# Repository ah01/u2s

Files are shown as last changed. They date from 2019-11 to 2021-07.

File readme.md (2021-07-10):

# USB To Serial Convertor Board

<p align="center">
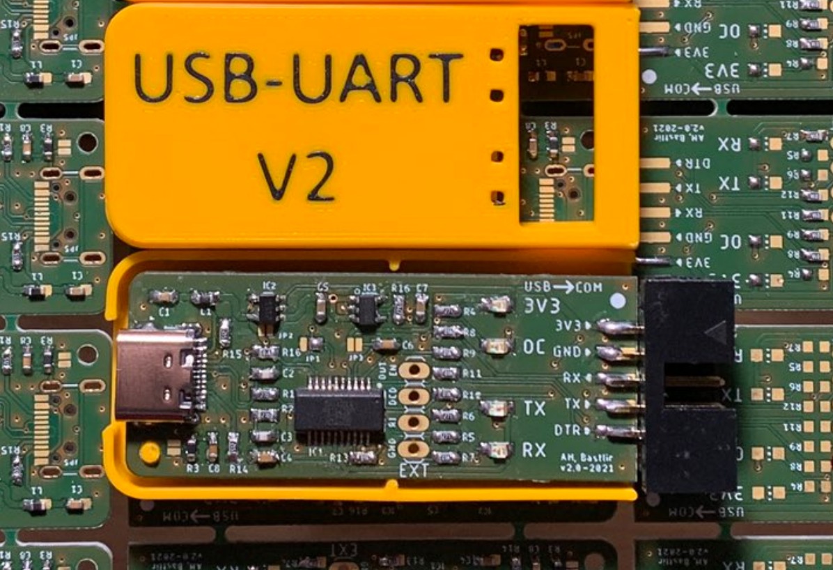
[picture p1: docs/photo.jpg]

</p>

## Features

- Reliable (no CH340 or FTDI232RL clones) – uses [FT231SX](https://ftdichip.com/products/ft231xs/) ([datasheet](https://ftdichip.com/wp-content/uploads/2020/08/DS_FT231X.pdf))
- 3V3 logic but 5V tolerant (no switching needed)
- On board 3V3 regulator (500 mA)
- Over current protection (suitable for development)
- Connector with key (so you can make idiot-proof cables) but DuPont friendly
- Both micro and USB-C connector (they are on opposite side of the board so you cannot use both in same time, but you will have more probability to find correct cable… you know Murphys Law)

## Connector

<p align="center">
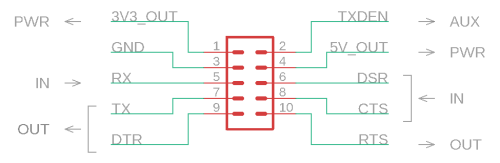
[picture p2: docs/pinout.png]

</p>

| Pin | Dir. | Description |
|:---:|:----:| ---|
| 1 |  | 3.3 V output (max 500 mA)¹ |
| 2 | OUT | Tx Data Enable² |
| 3 |  | GND |
| 4 |  | 5 V output (max 500 mA)¹ |
| 5 | IN | Rx |
| 6 | IN | DSR |
| 7 | OUT | Tx |
| 8 | IN | CTS |
| 9 | OUT | DTR |
| 10 | OUT | RTS |

¹ 500 mA is total maximum for 5 V  and 3.3 V output.

² Indicate transition for half-duplex communication (e.g. for RS-485).

## PCB

- [Schematics](https://raw.githubusercontent.com/ah01/u2s/master/docs/usb-to-serial.png) ([PDF](https://raw.githubusercontent.com/ah01/u2s/master/docs/usb-to-serial.pdf))
- [Sources for Eagle CAD](pcb)

<p align="center">
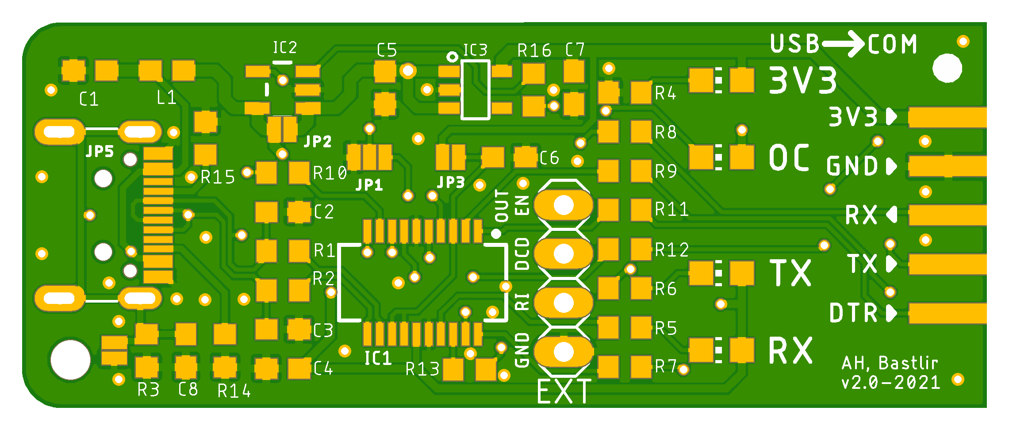
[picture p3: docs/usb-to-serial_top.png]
 &nbsp; &nbsp;
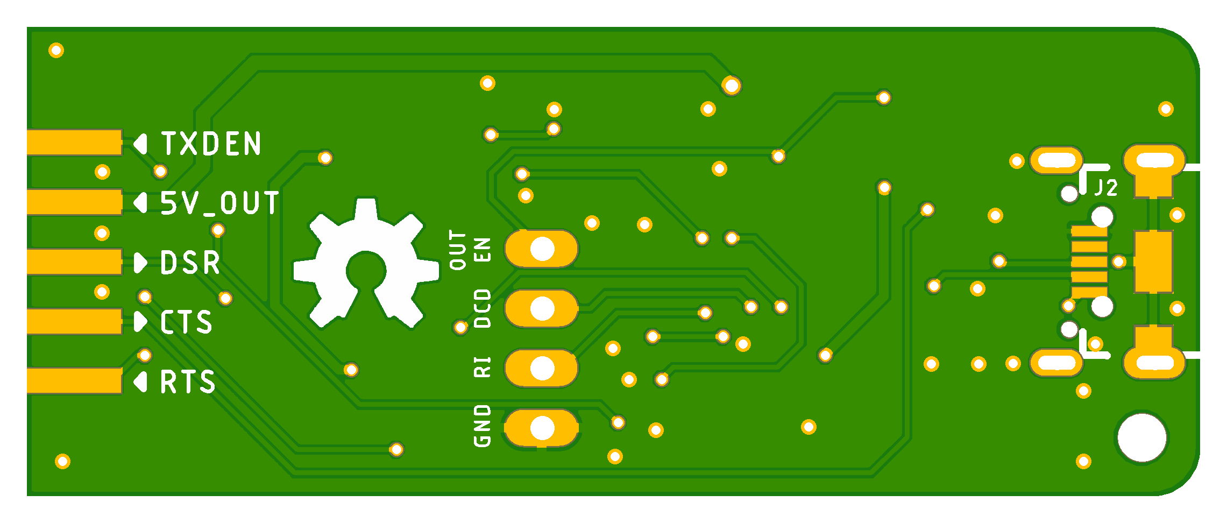
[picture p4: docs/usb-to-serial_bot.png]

</p>

## 3D Case

There are two variants for 3D prontable case:

- [With window](3Dcase/with_holes) – connector pinout is visible via window in case)

<p align="center">
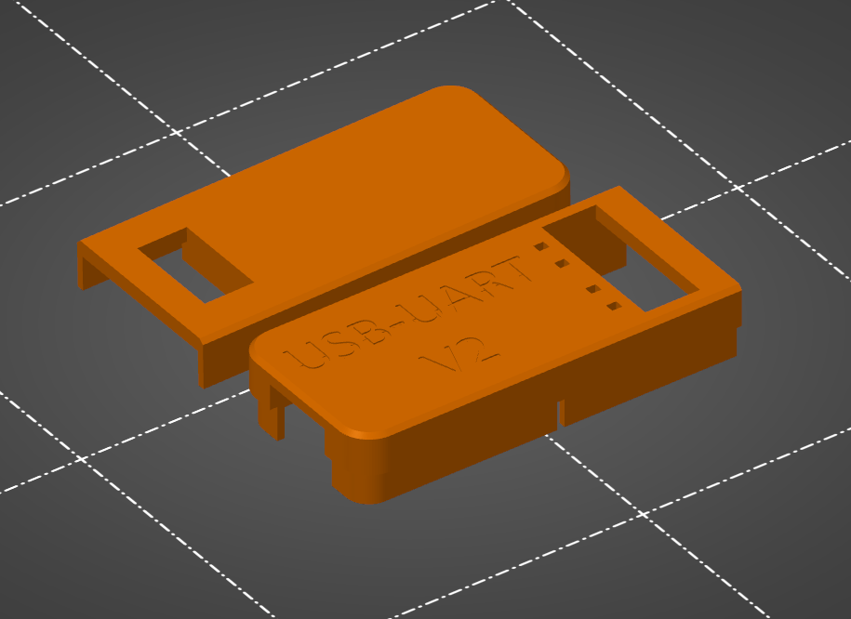
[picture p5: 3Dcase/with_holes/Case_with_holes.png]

</p>

- [Without window](3Dcase/no_holes) – connector pinout should be printed at back side as sticker

<p align="center">
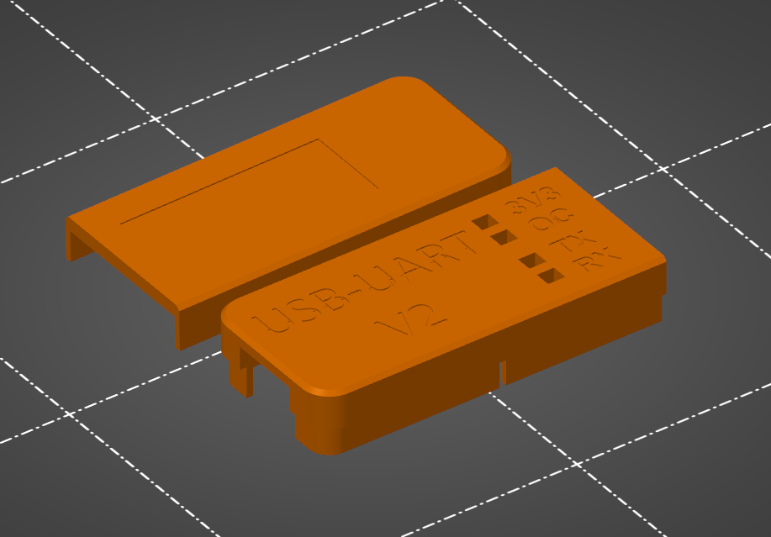
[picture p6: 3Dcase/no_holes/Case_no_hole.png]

</p>

## _Erratum_ Swapped TX and RX leds (FTDI configuration template)

⚠ Labels on Tx and Rx LEDs are swapped ([explenation](ft_prog/readme.md))

This problem can be fixed in SW configuration of FT231XS. There is template for [FT Prog](https://www.ftdichip.com/Support/Utilities.htm#FT_PROG) in [ft_prog directory](ft_prog).

## Credits

- [Bastlir](https://twitter.com/bastlir) - Update of design to v2 - USB-C connector, OverCurrent LED, other minor updates based on found issues, 3D case for V2
- [OK2UQL](https://twitter.com/ok2uqlGabo) - Case for 3D printing (see [tweet for example](https://twitter.com/ok2uqlGabo/status/1366835820972376068)) (V1)

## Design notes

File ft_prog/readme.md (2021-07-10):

# _Erratum_ Swapped TX and RX leds (FTDI configuration template)

<p align="center">
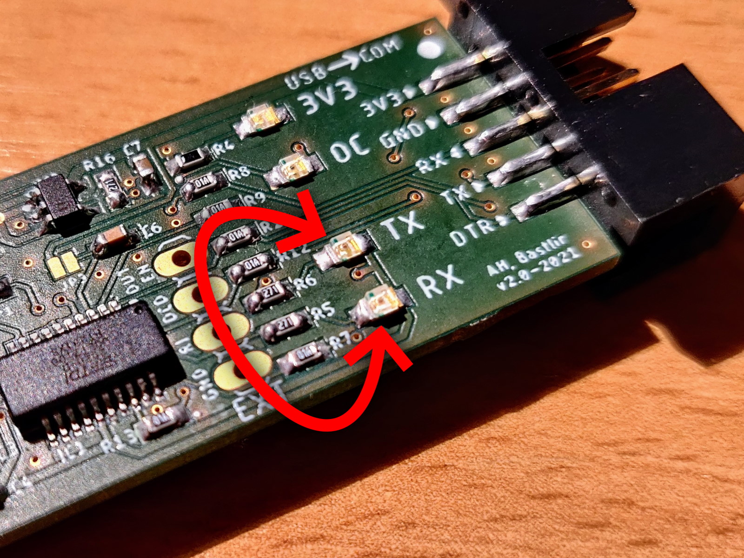
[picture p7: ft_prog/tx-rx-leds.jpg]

</p>

## Root Cause

In default configuration of FT231XS chip Tx and Rx LEDs indicate _activity on USB side_. Hovever for this convertor purpouse, we want to see Tx and Rx activity on _UART side (connector)_. There for Tx and Rx LEDs are swapped (Rx led blinks when data is coming out from Tx PIN).

datasheet

## Configuration

This problem can be fixed in SW configuration of FT231XS. Here is [`template.xml`](https://raw.githubusercontent.com/ah01/u2s/master/ft_prog/template.xml) for [FT Prog](https://www.ftdichip.com/Support/Utilities.htm#FT_PROG).

Only change is swap configuration for CBUS1 and CBUS2 signals.

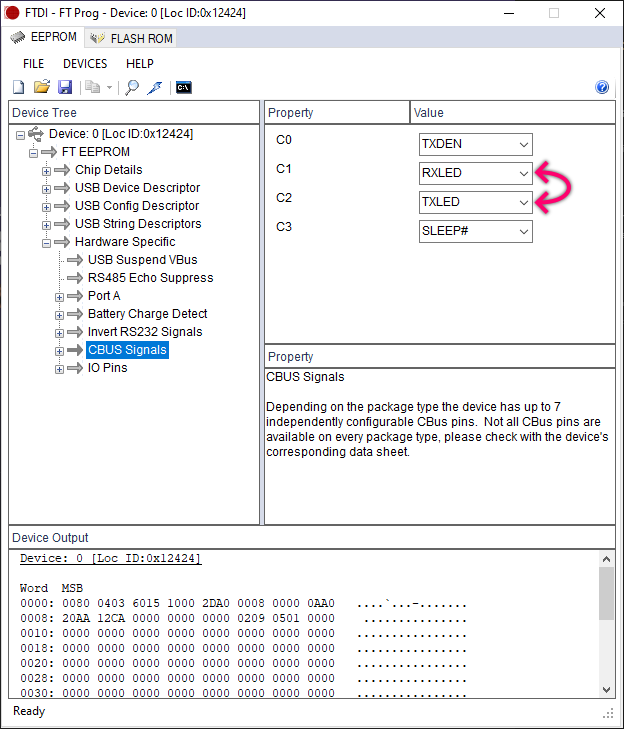
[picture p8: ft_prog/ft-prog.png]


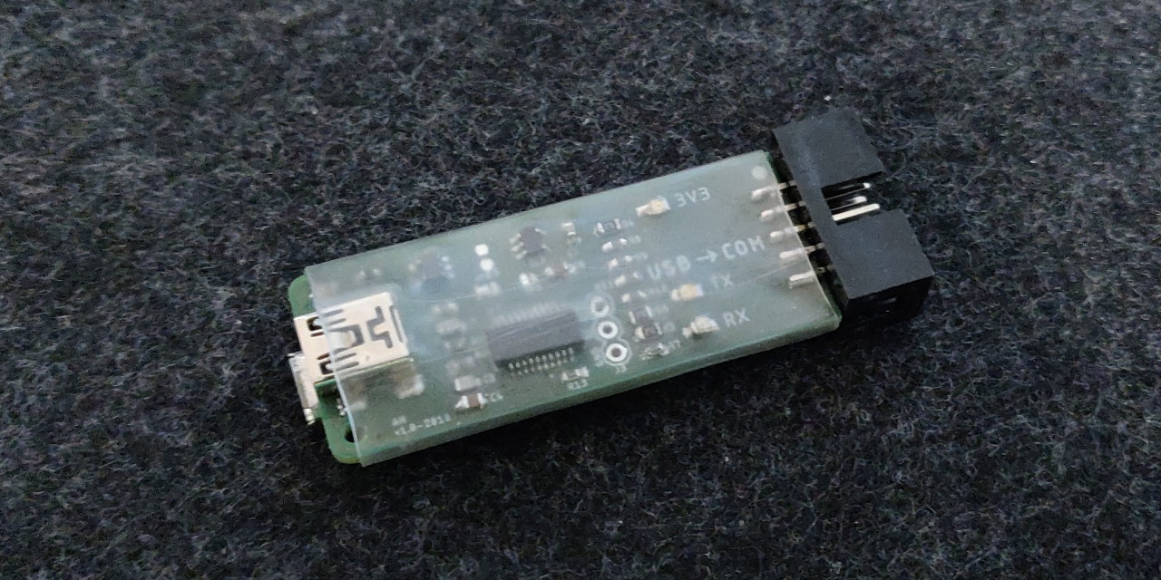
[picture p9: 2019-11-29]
docs/repository-open-graph-template.jpg

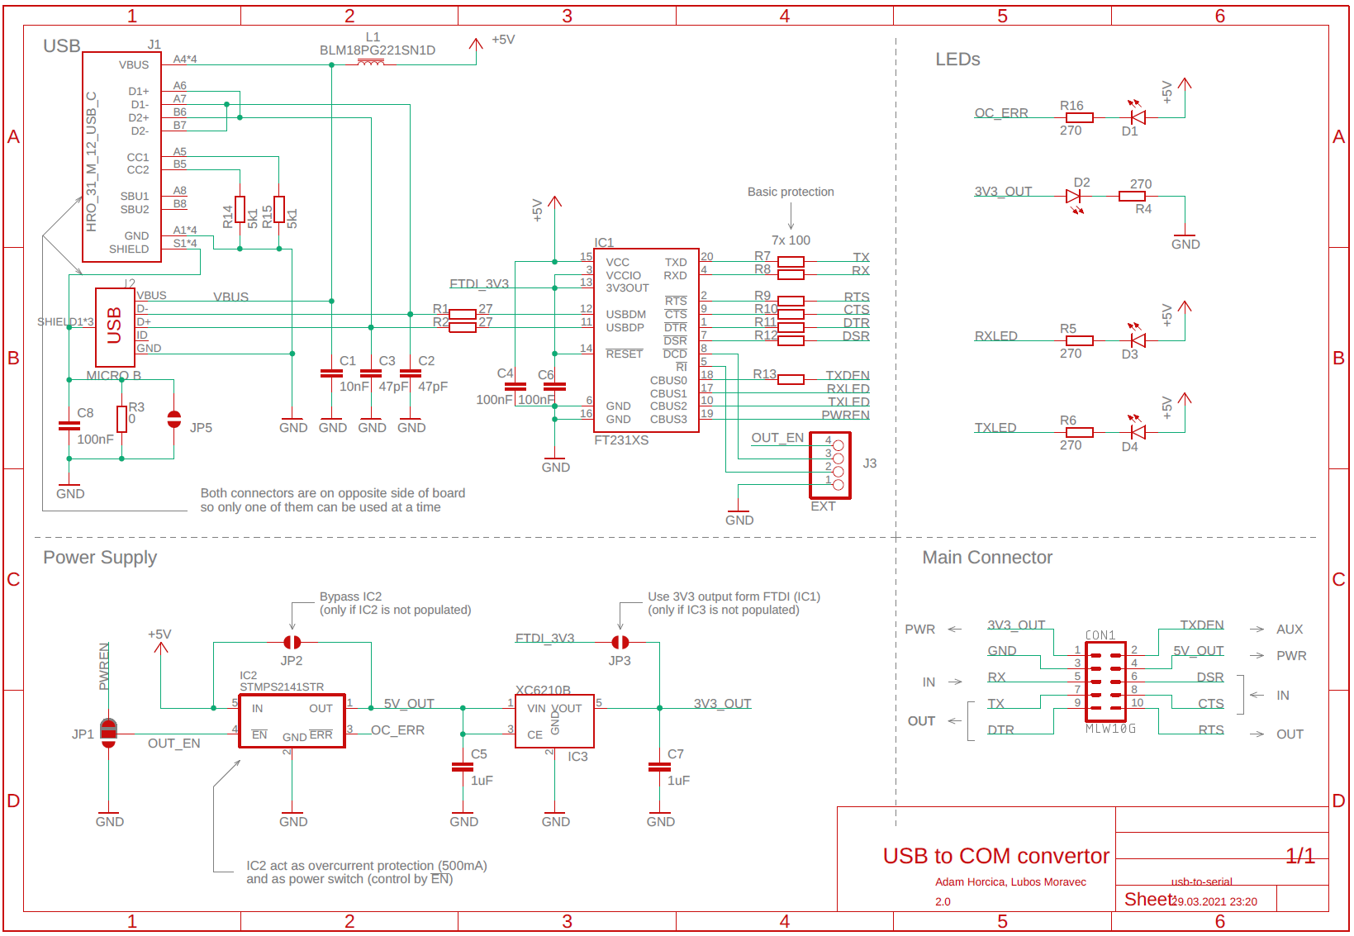
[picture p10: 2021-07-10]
docs/usb-to-serial.png

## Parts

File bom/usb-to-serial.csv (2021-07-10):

Qty | Value | Device | Package | Parts | Description | OC_FARNELL | OC_GME | ON_FARNELL | POPULARITY | PROD_ID | SPICEPREFIX | URL | VALUE | PRICE
4 |  | LEDCHIP-LED0805 | CHIP-LED0805 | D1, D2, D3, D4 | LED |  |  |  | 68 |  |  | https://cz.farnell.com/kingbright/kp-2012lsgc/led-green-0-8mcd-568nm-smd/dp/2463991 |  | 16,00 Kè
7 | 100 | R-EU_R0603 | R0603 | R7, R8, R9, R10, R11, R12, R13 | RESISTOR, European symbol |  |  |  | 70 |  | R | https://cz.farnell.com/multicomp/mcwr06x1000ftl/res-100r-1-0-1w-0603-thick-film/dp/2447227 |  | 0,91 Kè
3 | 100nF | C-EUC0603 | C0603 | C4, C6, C8 | CAPACITOR, European symbol |  |  |  | 73 |  | C | https://cz.farnell.com/kemet/c0603c104m4ractu/cap-0-1-f-16v-20-x7r-0603/dp/2581045 |  | 0,99 Kè
1 | 10nF | C-EUC0603 | C0603 | C1 | CAPACITOR, European symbol |  |  |  | 73 |  | C | https://cz.farnell.com/walsin/0603b103k500ct/cap-0-01-f-50v-10-x7r-0603/dp/2496828 |  | 0,44 Kè
2 | 1uF | C-EUC0603 | C0603 | C5, C7 | CAPACITOR, European symbol |  |  |  | 73 |  | C | https://cz.farnell.com/samsung-electro-mechanics/cl10a105ka8nnnc/cap-1uf-25v-mlcc-0603/dp/3013382 |  | 1,24 Kè
2 | 27 | R-EU_R0603 | R0603 | R1, R2 | RESISTOR, European symbol |  |  |  | 70 |  | R | https://cz.farnell.com/multicomp/mcwr06x27r0ftl/res-27r-1-0-1w-0603-thick-film/dp/2447316 |  | 0,32 Kè
4 | 270 | R-EU_R0603 | R0603 | R4, R5, R6, R16 | RESISTOR, European symbol |  |  |  | 70 |  | R | https://cz.farnell.com/multicomp/mcwr06x2700ftl/res-270r-1-0-1w-thick-film/dp/2447314 |  | 0,56 Kè
2 | 47pF | C-EUC0603 | C0603 | C2, C3 | CAPACITOR, European symbol |  |  |  | 73 |  | C | https://cz.farnell.com/yageo/cc0603jrnpo9bn470/cap-47pf-50v-5-c0g-np0-0603/dp/722042 |  | 1,30 Kè
2 | 5k1 | R-EU_R0603 | R0603 | R14, R15 | RESISTOR, European symbol |  |  |  | 70 |  | R | https://cz.farnell.com/multicomp/mcwr06x5101ftl/res-5k1-1-0-1w-0603-thick-film/dp/2447404 |  | 0,30 Kè
2 | BLM18PG221SN1D | FERRITE_BEAD-0603 | 603 | L1, R3 | Ferrite Bead (blocks, cores, rings, chokes, etc.) | 1515740 |  | BLM18PG221SN1D |  | NDUC-07859 |  | https://cz.farnell.com/murata/blm18pg221sn1d/ferrite-bead-0-1ohm-1-4a-0603/dp/1515740 |  | 1,60 Kè
1 | FT231XS | FT231XS | SSOP20_L | IC1 | FTDI FT231X Full Speed USB to Full-handshake UART |  |  |  |  | IC-11524 |  | https://cz.farnell.com/ftdi/ft231xs/i-f-usb2-0-fs-to-f-l-h-s-uart/dp/2081328 |  | 57,99 Kè
1 | HRO_31_M_12_USB_C | HRO_31_M_12_USB_C | HRO_31_M_12_USB_C | J1 | USB Shielded I/O Receptacle; Type C; Right Angle; Surface Mount; Gold over Nickel |  |  |  |  |  |  | https://lcsc.com/product-detail/USB-Connectors_Korean-Hroparts-Elec-TYPE-C-31-M-12_C165948.html |  | 10,00 Kè
1 | MICRO B | USB_MICRO-B_FEMALE-SMT | USB-B-MICRO-SMD | J2 | USB Type Micro-B Connector |  |  |  |  | CONN-11752 |  | https://cz.farnell.com/amphenol-icc-fci/10104110-0001lf/micro-usb-2-0-type-b-receptacle/dp/2293753 |  | 13,91 Kè
1 | MLW10G | MLW10G | MLW10G | CON1 | Connector Konektor 2,54mm, 2x5 |  | 800-035 |  |  |  |  | https://cz.farnell.com/multicomp/mc-254-10-00-st-dip/connector-header-10pos-2row-2/dp/2843527 |  | 4,52 Kè
1 | STMPS2141STR | STMPS2141STR | SOT23-5 | IC2 |  |  |  |  |  |  |  | https://cz.farnell.com/stmicroelectronics/stmps2151str/power-switch-1ch-500ma-sot23-5/dp/1842616 |  | 7,32 Kè
1 | XC6210B332MR | XC6210 | SOT-23-5 | IC3 |  |  |  |  |  |  |  | https://cz.farnell.com/torex/xc6210b332mr/ic-v-reg-cmos-ldo-3-3v-smd-6210/dp/1057803 |  | 17,64 Kè

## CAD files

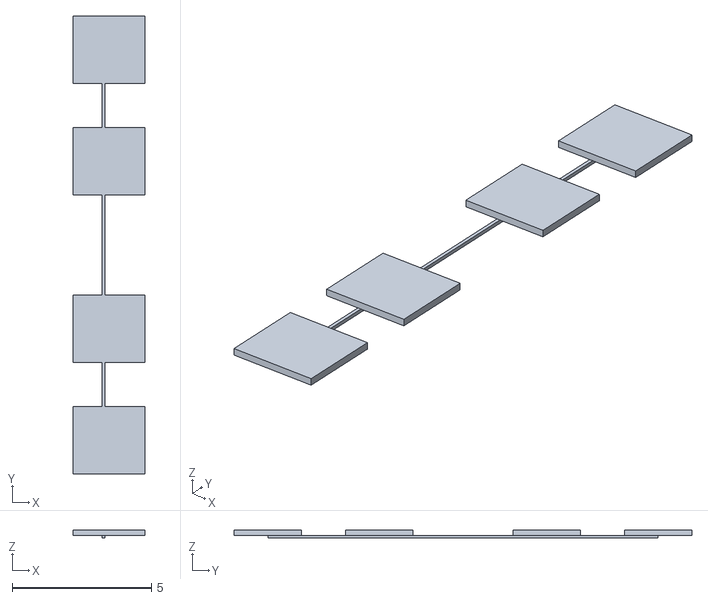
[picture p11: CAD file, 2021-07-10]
3Dcase/no_holes/Case_u2sV2_1_LED.stl
2.60 x 16.4 x 0.3

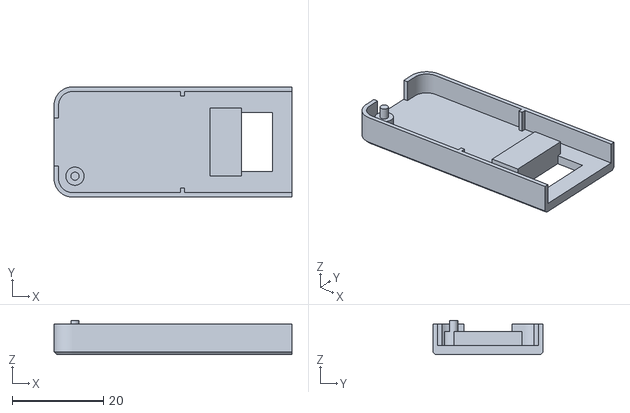
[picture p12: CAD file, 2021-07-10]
3Dcase/with_holes/Case_u2sV2_2.stl
52.2 x 24.2 x 7.50

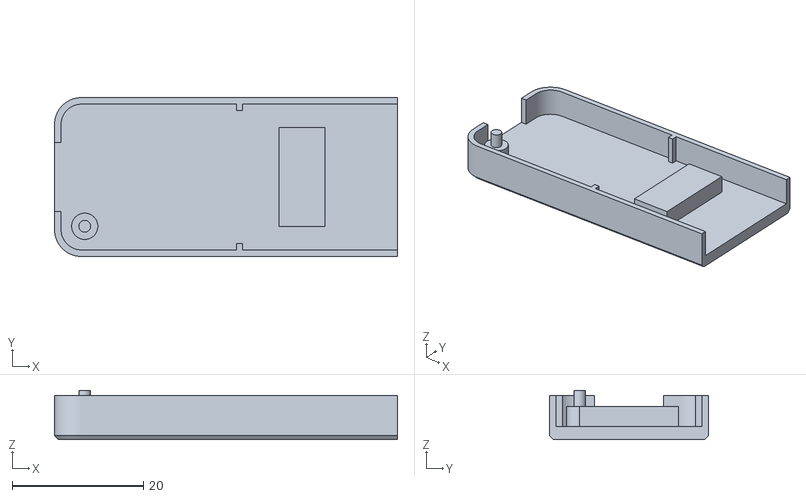
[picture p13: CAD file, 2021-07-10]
3Dcase/no_holes/Case_u2sV2_2.stl
52.2 x 24.2 x 7.50

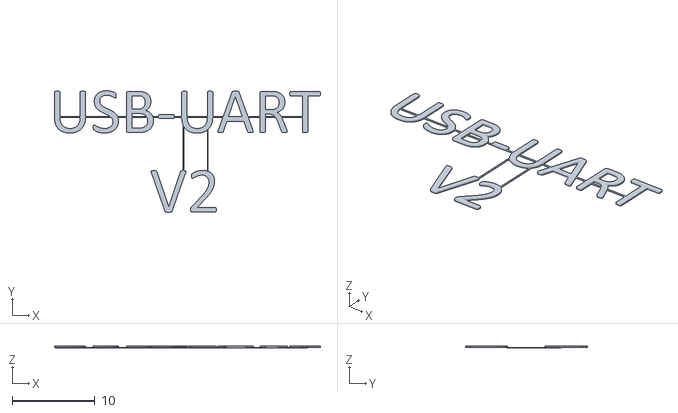
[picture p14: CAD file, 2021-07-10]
3Dcase/with_holes/Case_u2sV2_1_letters.stl
32.1 x 14.7 x 0.3

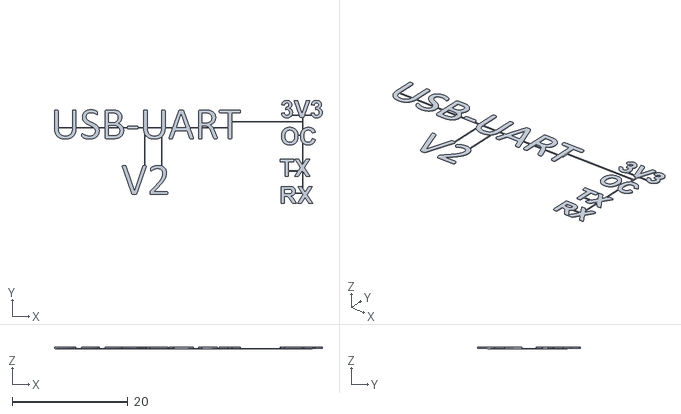
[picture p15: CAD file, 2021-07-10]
3Dcase/no_holes/Case_u2sV2_1_letters.stl
46.2 x 17.9 x 0.3

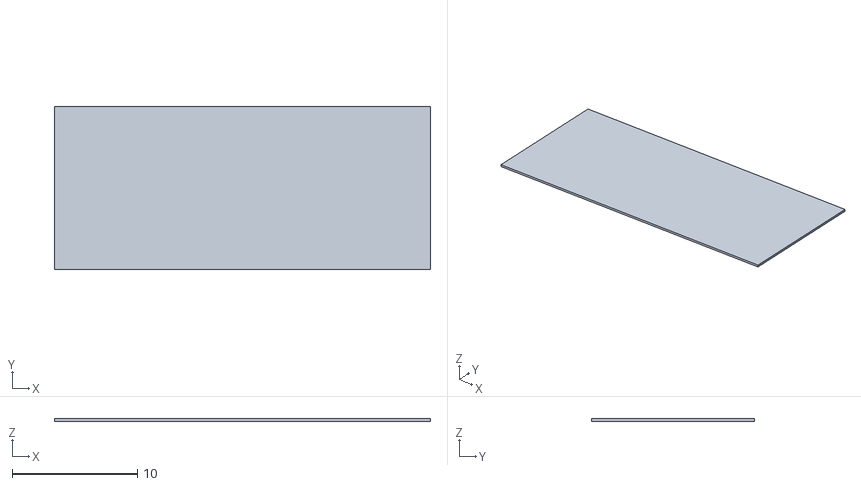
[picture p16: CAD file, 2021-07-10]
3Dcase/no_holes/Case_u2sV2_2_writebox.stl
30.0 x 13.0 x 0.2

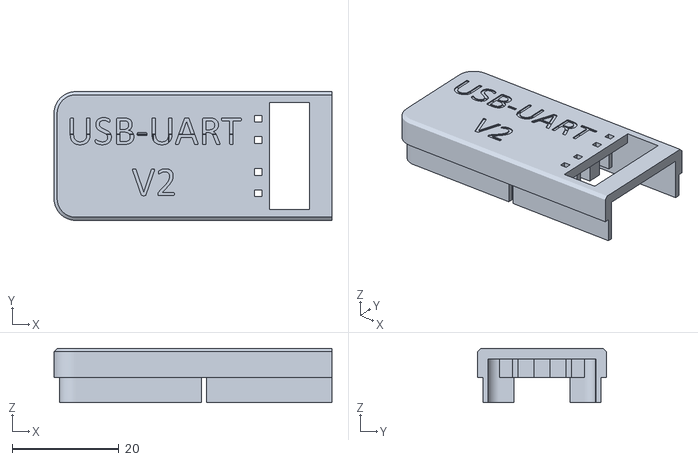
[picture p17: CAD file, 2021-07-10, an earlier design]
3Dcase/with_holes/Case_u2sV2_1.stl
52.2 x 24.2 x 10.2

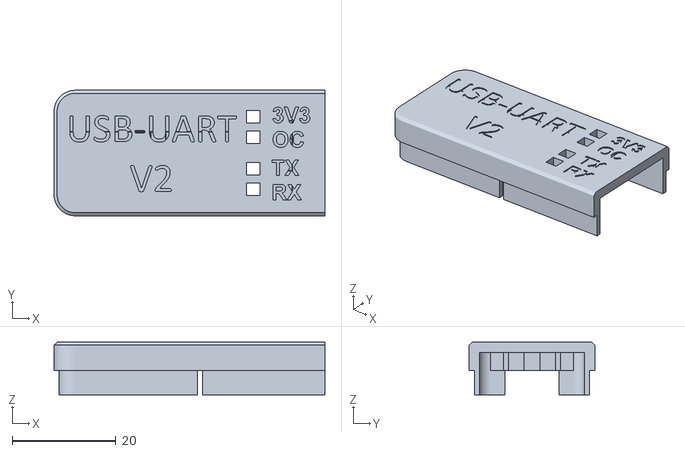
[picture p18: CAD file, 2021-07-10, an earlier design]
3Dcase/no_holes/Case_u2sV2_1.stl
52.2 x 24.2 x 10.2

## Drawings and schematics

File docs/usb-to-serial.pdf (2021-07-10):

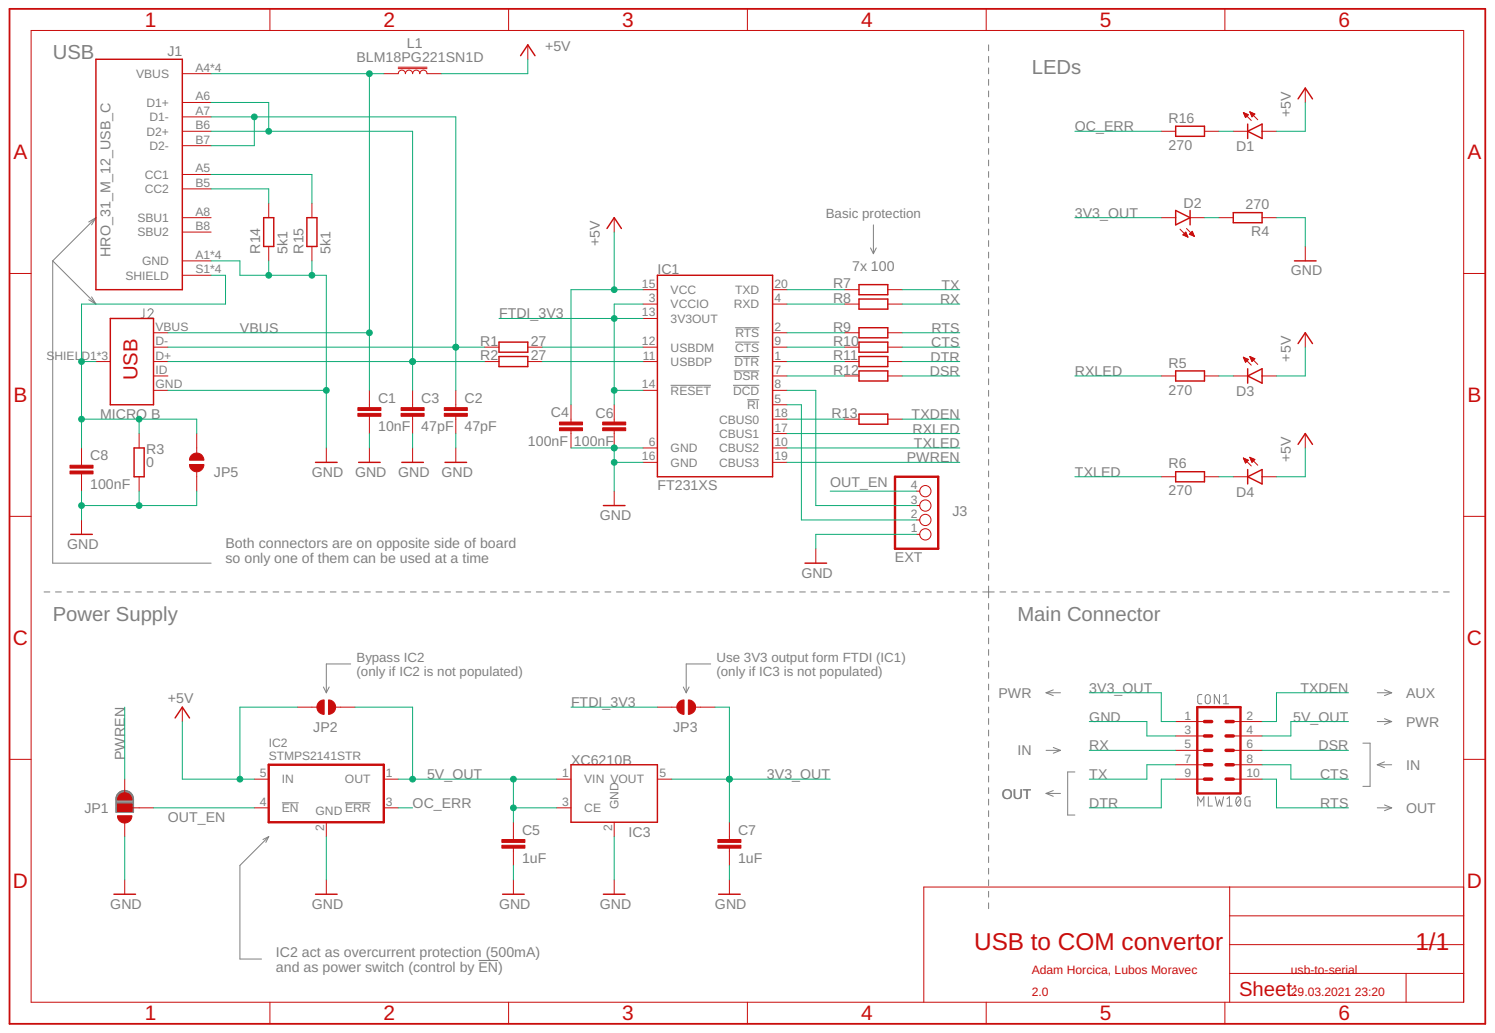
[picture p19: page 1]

Both connectors are on opposite side of board
so only one of them can be used at a time Bypass IC2

Use 3V3 output form FTDI (IC1)
(only if IC3 is not populated)

(only if IC2 is not populated)

2.0 USB to COM convertor Adam Horcica, Lubos Moravec

IC2 act as overcurrent protection (500mA) and as power switch (control by EN)

Sheet:

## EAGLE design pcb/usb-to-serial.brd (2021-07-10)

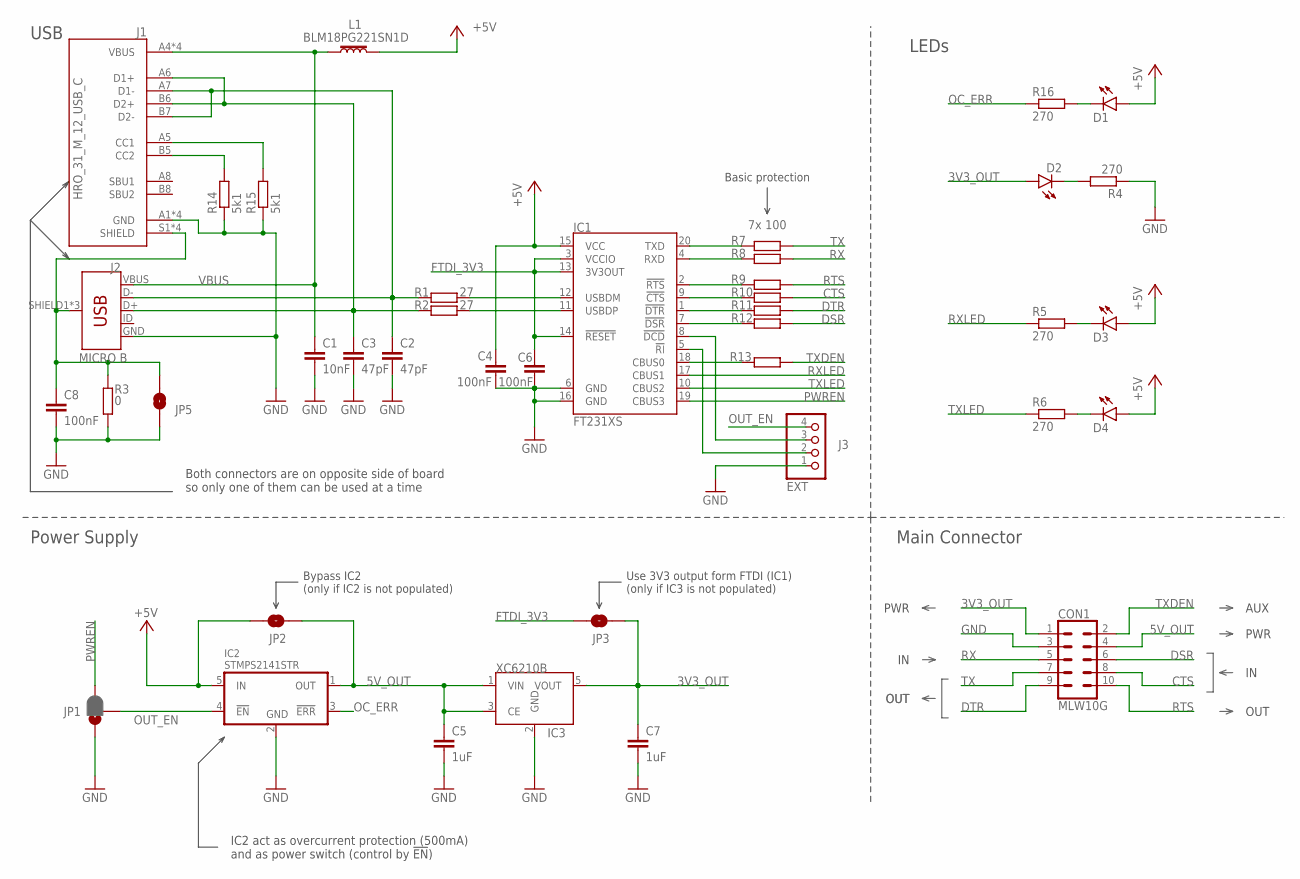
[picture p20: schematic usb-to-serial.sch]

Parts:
C1: 10nF; C0603
C2, C3: 47pF; C0603
C4, C6, C8: 100nF; C0603
C5, C7: 1uF; C0603
CON1: MLW10G
D1, D2, D3, D4: LEDCHIP-LED0805; CHIP-LED0805
EXT: J3; 1X04
IC1: FT231XS; SSOP20_L
IC2: STMPS2141STR; SOT23-5
IC3: XC6210B332MR; SOT-23-5
J1: HRO_31_M_12_USB_C
J2: MICRO B; USB-B-MICRO-SMD
JP1: JUMPER-SMT_3_1-NC_PASTE_NO-SILK; SMT-JUMPER_3_1-NC_PASTE_NO-SILK
JP2, JP3, JP5: JUMPER-SMT_2_NO_NO-SILK; SMT-JUMPER_2_NO_NO-SILK
L1: BLM18PG221SN1D; 0603
R1, R2: 27; R0603
R3: 0; R0603
R4, R5, R6, R16: 270; R0603
R7, R8, R9, R10, R11, R12, R13: 100; R0603
R14, R15: 5k1; R0603

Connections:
3V3_OUT: C7.1, CON1.1, D2.A, IC3.5 (VOUT), JP3.2
5V_OUT: C5.1, CON1.4, IC2.1 (OUT), IC3.1 (VIN), IC3.3 (CE), JP2.2
+5V: C4.1, D1.A, D3.A, D4.A, IC1.15 (VCC), IC2.5 (IN), JP2.1, L1.1
CTS: CON1.8, R10.2
DCD: EXT.3, IC1.8 (!DCD)
DSR: CON1.6, R12.2
DTR: CON1.9, R11.2
FTDI_3V3: C6.1, IC1.3 (VCCIO), IC1.13 (3V3OUT), IC1.14 (!RESET), JP3.1
GND: C1.2, C2.2, C3.2, C4.2, C5.2, C6.2, C7.2, C8.2, CON1.3, EXT.1, IC1.6 (GND), IC1.16 (GND), IC2.2 (GND), IC3.2 (GND), J1.A1 (GND), J1.A12 (GND), J1.B1 (GND), J1.B12 (GND), J2.GND, JP1.1, JP5.1, R3.1, R4.1, R14.1, R15.1
unnamed: IC1.18 (CBUS0), R13.1
unnamed: J1.A5 (CC1), R15.2
unnamed: IC1.20 (TXD), R7.1
unnamed: D2.C, R4.2
unnamed: J1.B5 (CC2), R14.2
unnamed: C8.1, J1.S1 (SHIELD), J1.S2 (SHIELD), J1.S3 (SHIELD), J1.S4 (SHIELD), J2.SHIELD1 (SHIELD), J2.SHIELD2 (SHIELD), J2.SHIELD3 (SHIELD), JP5.2, R3.2
unnamed: D3.C, R5.2
unnamed: D4.C, R6.2
unnamed: D1.C, R16.2
unnamed: IC1.4 (RXD), R8.1
unnamed: IC1.2 (!RTS), R9.1
unnamed: IC1.9 (!CTS), R10.1
unnamed: IC1.1 (!DTR), R11.1
unnamed: IC1.7 (!DSR), R12.1
OC_ERR: IC2.3 (!ERR), R16.1
OUT_EN: EXT.4, IC2.4 (!EN), JP1.2
PWREN: IC1.19 (CBUS3), JP1.3
RI: EXT.2, IC1.5 (!RI)
RTS: CON1.10, R9.2
RX: CON1.5, R8.2
RXLED: IC1.17 (CBUS1), R5.1
TX: CON1.7, R7.2
TXDEN: CON1.2, R13.2
TXLED: IC1.10 (CBUS2), R6.1
USBD2_N: IC1.12 (USBDM), R1.2
USBD2_P: IC1.11 (USBDP), R2.2
USBD_N: C2.1, J1.A7 (D1-), J1.B7 (D2-), J2.D-, R1.1
USBD_P: C3.1, J1.A6 (D1+), J1.B6 (D2+), J2.D+, R2.1
VBUS: C1.1, J1.A4 (VBUS), J1.A9 (VBUS), J1.B4 (VBUS), J1.B9 (VBUS), J2.VBUS, L1.2

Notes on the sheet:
USB
LEDs
Main Connector
Power Supply
Use 3V3 output form FTDI (IC1) (only if IC3 is not populated)
Both connectors are on opposite side of board so only one of them can be used at a time
7x 100
Bypass IC2 (only if IC2 is not populated)
OUT
PWR
AUX
Basic protection
IC2 act as overcurrent protection (500mA) and as power switch (control by !EN!)

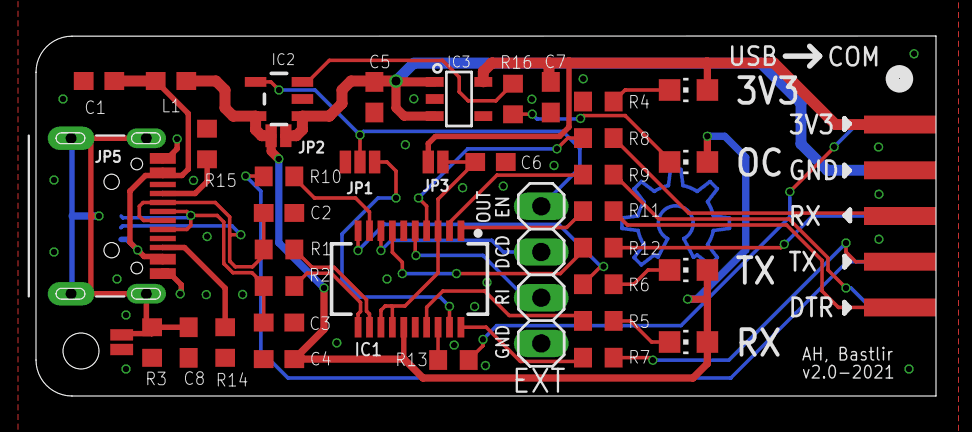
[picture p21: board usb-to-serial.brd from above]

Board: 2 copper layers, 50.0 x 20.0 mm, 40 parts (1 on the bottom side), 38 nets.

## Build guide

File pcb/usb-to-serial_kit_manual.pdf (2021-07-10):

Plan n. | Qty | Value | Parts
| 4 | | D1, D2, D3, D4
1 | 2 | 27 | R1, R2
2 | 7 | 100 | R7, R8, R9, R10, R11, R12, R13
3 | 4 | 270/1k8 | R4, R5, R6, R16
4 | 2 | 5k1 | R14, R15
5 | 2 | 47pF | C2, C3
6 | 1 | 10nF | C1
7 | 3 | 100nF | C4, C6, C8
8 | 2 | 1uF | C5, C7
9 | 2 | BLM18PG221SN1D | L1, R3
10 | 1 | FT231XS | IC1
11 | 1 | STMPS2141STR | IC2
12 | 1 | XC6210B332MR | IC3
13 | 1 | HRO_31_M_12_USB_C | J1
14 | 1 | MICRO B | J2
15 | 1 | MLW10G | CON1

If you will use all components, connect JP1 in position visible below. LED 3V3 + R4
LED OC + R16
LED TX + R6
LED RX + R5
All files are available on: https://github.com/Bastlirovo/u2s , original v1 repo https://github.com/ah01/u2s

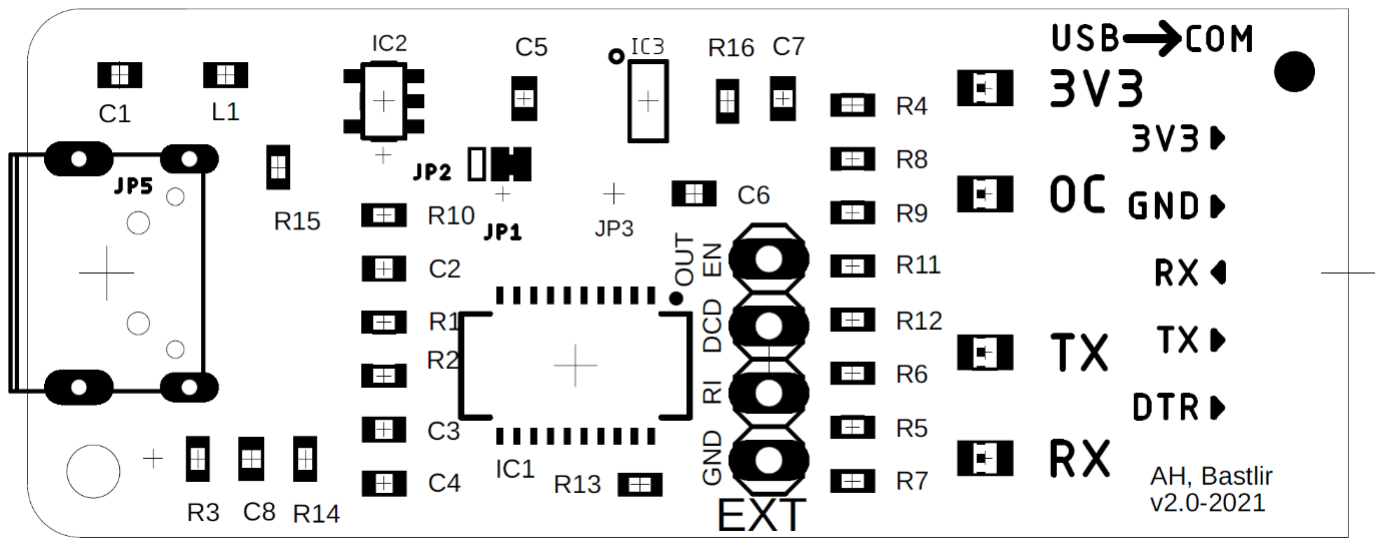
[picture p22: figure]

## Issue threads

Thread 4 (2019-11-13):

Add indication LED to error output of IC2 (over current shutdown)

ah01, 2019-11-13:

Closed 2021-07-10.

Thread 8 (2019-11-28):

Test power dissipation of IC3 under full load

ah01, 2019-11-28:
Test behavior of the board under full load of 3.3 V output. Goal is to determine maximum rating for short and long term load (power dissipation of IC 3, operating temperature, stability etc.)

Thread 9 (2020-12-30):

Replace mini USB connector with USB-C

ah01, 2020-12-30:

Closed 2021-07-10.

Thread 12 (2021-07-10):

Swap Tx and Rx LED labels

ah01, 2021-07-10:
See https://github.com/ah01/u2s/blob/master/ft_prog/readme.md

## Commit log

2019-11-03 Source files for PCB version 1.0
    [usb-to-serial.brd, usb-to-serial.csv, usb-to-serial.sch]
2019-11-29 Add link to interactive BOM
2021-07-05 Dev v2 merge to master (#1)
    * Update to v2
    Changes from Issues:
    - Pinout on top/bottom silkscreen
    - Add indication LED to error output of IC2 (over current shutdown)
    - Add EN pin of IC2 to EXT connector
    - Add OSHW logo to silkscreen
    Replace mini USB connector with USB-C
    - Replace IC3 with XC6210
    * Polishing of v2 according to notes from Adam, added schematic in PDF, gerber ZIP package.
    * Update of BOM for v2 with Farnell links and prices
    * 3D models added, update of Readme and kit manual for v2.
    * Update of documentation pictures, readme
    [Case_u2sV2_1.stl, Case_u2sV2_1_LED.stl, Case_u2sV2_1_letters.stl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]
2021-07-10 Improve PCB image size
2021-07-10 Add info about Tx and Rx led swap + fix template
2021-07-10 Add 3D case info
    [Case_u2sV2_1.stl, Case_u2sV2_1_LED.stl, Case_u2sV2_1_letters.stl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]

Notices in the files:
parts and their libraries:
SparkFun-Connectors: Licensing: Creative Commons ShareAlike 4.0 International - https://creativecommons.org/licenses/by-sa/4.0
